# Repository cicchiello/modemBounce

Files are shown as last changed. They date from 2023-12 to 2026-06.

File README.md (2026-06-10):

# modemBounce

A home-network monitor that automatically power-cycles the cable modem or Wi-Fi router when connectivity problems are detected. The device periodically pings four targets — router, modem, an internet IP, and a DNS hostname. If any check fails repeatedly, the corresponding device is power-cycled through a normally-closed solid-state relay and an alert email is sent.

The hardware is an **Adafruit Feather M0** (SAMD21 + ATWINC1500 Wi-Fi), housed in a laser-cut enclosure. See `schematic.txt` for the circuit. An older Raspberry Pi proof-of-concept lives in `rpi/` but is not maintained.

---

## Hardware

### Bill of Materials

| Qty | Component | Notes |
|-----|---|---|
| 1 | Adafruit Feather M0 WiFi (ATWINC1500) | MCU + Wi-Fi |
| 2 | Berm KB25DA normally-closed SSR | 3–32 V DC input, 25 A AC output |
| 2 | 2N2222 NPN transistor | Low-side SSR driver (one per SSR) |
| 2 | 2.2 kΩ resistor, 1/4 W | 2N2222 base resistor |
| 1 | RGB LED, 5 mm, common cathode | Status indicator |
| 1 | 470 Ω resistor, 1/4 W | LED common-cathode current-limiting |
| 1 | Tactile push button, normally open | Reset + factory-reset input (see schematic) |
| 1 | Capacitor | AC-couples button press to Feather RESET pin for momentary reset pulse |
| 1 | USB wall adapter (disassembled) | Wired internally to post-fuse AC; 5 V DC output wired directly to Feather VUSB header pin |
| 1 | Protoboard | Hand-assembled PCB carrying the Feather and all low-voltage components |

See `schematic.txt` for wiring details. The mains hot feed passes through a 10 A fuse before splitting to both SSRs. Neutral runs straight through to both outlets; only the hot conductor is switched.

### Enclosure

The enclosure is entirely laser-cut from **Delrin** (acetal/POM), chosen for its electrical insulation and self-extinguishing properties. All panels and internal dividers are Delrin; there are no metal structural parts.

The interior is divided into **three compartments** by two internal divider panels:

| Compartment | Contents |
|---|---|
| Low-voltage | Protoboard PCB (Feather M0 + SSR drivers + LED + reset button) |
| High-voltage mixed | SSRs, disassembled USB wall-wart, incoming mains cable |
| AC outlets | Modem and router plugs, 10 A fuse |

The primary intent is HV/LV isolation; three compartments emerged naturally from the physical layout of the components.

FreeCAD source (`bouncy_v1.2.FCStd`) and laser-cut SVG panel exports are in `enclosure/svg-output/`. Interior divider profiles are `interior-short-v1.2.svg` and `interior-long-v1.2.svg`.

---

## Software components

| Location | Description |
|---|---|
| `feather/bouncy/` | Arduino/C++ firmware (current implementation) |
| `iot-services/email-relay/` | LAN email-relay service, Docker, runs on pi-nas |
| `rpi/` | Legacy Raspberry Pi proof-of-concept — not maintained |

---

## Firmware setup

### Arduino IDE libraries

Install via *Sketch → Include Library → Manage Libraries* or as ZIP files:

- **WiFi101** — ATWINC1500 driver (Arduino)
- **FlashStorage_SAMD** — EEPROM emulation in SAMD21 flash
- **arduinolibs** suite by rweather — provides `Crypto`, `AES`, `CTR`, `SHA256`

Board: *Adafruit SAMD Boards → Adafruit Feather M0*

### Secrets file

Edit `feather/bouncy/arduino_secrets.h`:

| Symbol | Purpose |
|---|---|
| `SECRET_SSID` / `SECRET_PASS` | Home Wi-Fi creds — used only in non-PROD test modes for direct-connect |
| `LOG_HOST/PORT/PATH`, `SECRET_LOGGING_KEY` | HTTP log service on pi-nas (port 8091) |
| `EMAIL_HOST/PORT/PATH`, `SECRET_EMAIL_KEY` | email-relay service on pi-nas (port 8093) |
| `SECRET_WIFI_ENC_KEY` | 16-byte AES-128 key for flash credential storage |
| `SECRET_WIFI_MAC_KEY` | 32-byte HMAC-SHA256 key for flash credential authentication |

Generate random keys:
```bash
openssl rand -hex 16    # → SECRET_WIFI_ENC_KEY (format as byte array)
openssl rand -hex 32    # → SECRET_WIFI_MAC_KEY
openssl rand -hex 24    # → shared keys for logging and email-relay
```

The `SHARED_KEY` value in `iot-services/email-relay/.env` must match `SECRET_EMAIL_KEY`.

### Build and flash

1. Open `feather/bouncy/bouncy.ino` in Arduino IDE.
2. Select *Tools → Board → Adafruit Feather M0*.
3. Select the correct serial port.
4. Click **Upload**.

---

## First-time setup (provisioning)

On first boot — or after a factory reset — there are no stored Wi-Fi credentials. The device enters provisioning mode automatically.

1. **LED goes blinking-red.** The Feather broadcasts a Wi-Fi network named **`Bouncy-Setup`**.
2. Connect a phone or laptop to `Bouncy-Setup`.
3. Open a browser and go to **`http://192.168.1.1/`**.
4. Enter your home Wi-Fi SSID and password.
5. Choose a **run mode** — use *Normal production mode* for permanent installation.
6. Tap **Save WiFi Settings**. The LED goes blue as the device connects.
7. Disconnect from `Bouncy-Setup`. The Feather joins your home network, **LED turns green**, and monitoring begins.

Run mode applies to the current session only; the device boots into `PROD` mode if it has valid credentials persisted. Test modes are intended for bench testing.

---

## Factory reset

The reset button is AC-coupled through a capacitor to the Feather's RESET pin, so any press immediately reboots the device. On startup the firmware checks whether the button is still held (via pin **A0**, INPUT_PULLUP):

- **Brief press / release before 5 s** — normal reboot, credentials intact.
- **Hold for 5 s** — Stored Wi-Fi credentials are erased and the device re-enters provisioning mode (with flasing-red indicator).

---

## Normal operation

| LED | Meaning |
|-----|---|
| Green | Connected and monitoring normally |
| Blue | Connecting / reconnecting to Wi-Fi |
| Red (flashing) | Provisioning mode — AP `Bouncy-Setup` is up; open `http://192.168.1.1` to configure |
| Red (steady) | Problem detected; bouncing a device |

The device checks connectivity every **30 minutes** (2 minutes in test modes):

1. Wi-Fi AP connection
2. Ping router — `10.0.0.1`
3. Ping modem — `192.168.100.1`
4. Ping internet — `8.8.8.8`
5. DNS resolution — `google.com`

Each failing check is retried up to **5 times** at 1-minute intervals. After 5 consecutive failures:

- Router ping failure → router is power-cycled
- Modem / internet / DNS failure → cable modem is power-cycled

After a bounce, the device waits **3.5 minutes** for the device to reinitialize, then sends an alert email and resumes monitoring.

---

## email-relay service

The email-relay is a small HTTP service on **pi-nas** (`10.0.0.214:8093`) that lets the Feather send alert emails without embedding SMTP credentials in the firmware. It runs in Docker.

See [`iot-services/email-relay/README.md`](iot-services/email-relay/README.md) for full setup, configuration, and testing instructions.

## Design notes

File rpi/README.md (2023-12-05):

modemBounce.py
   - executed every 15 minutes (per crontab)
      (It can't be much more frequently without more work -- the whole cycle takes max about 10 minutes)
   - when a problem is detected, it will attempt to power down, then back up the modem's A/C outlet

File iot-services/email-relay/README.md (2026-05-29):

# email-relay

`email-relay` is a small LAN-only HTTP service that lets the Feather M0 send monitoring emails without embedding SMTP credentials in the firmware.

The Feather sends a simple HTTP `POST` request to `pi-nas`; this service validates a shared key and sends the email through the configured SMTP account.

---

## Purpose

The Feather M0 is a small monitoring device. It should be able to report notable events by email, but it should **not** know the SMTP server password.

This service provides a local relay:

```text
Feather M0
  HTTP POST /send
  shared-key header
  JSON body with subject/message
        |
        v
pi-nas email-relay
  validates request
  sends email using SMTP credentials stored on pi-nas
        |
        v
configured email recipients
```

---

## Host environment

This service is intended to run on:

- Host: `pi-nas`
- Hardware: Raspberry Pi 5
- NAS manager: OpenMediaVault
- Container runtime: Docker / OMV Compose
- LAN IP: `10.0.0.214`
- Service port: `8093`

The service listens on:

```text
http://10.0.0.214:8093/send
```

Only HTTP `POST` to `/send` is supported.

---

## Repository layout

```text
~/workspace/modemBounce/iot-services/email-relay/
  Dockerfile
  docker-compose.yml
  email_relay.py
  .env              # local secrets; not committed
  .env.example      # documented example; safe to commit
  .gitignore
  README.md
```

Convenience symlink:

```text
/opt/pi-nas-services/email-relay -> /home/joe/workspace/modemBounce/iot-services/email-relay
```

The git repo is the preferred authoritative source for the service.

---

## API

### Endpoint

```http
POST /send
```

### Required header

```http
X-Email-Relay-Key: <shared-key>
```

The key is stored in `.env` as:

```text
SHARED_KEY=...
```

The Feather firmware should store the same value in `arduino_secrets.h`, for example:

```cpp
#define SECRET_EMAIL_RELAY_KEY "..."
```

### Request body

The request body is JSON:

```json
{
  "subject": "Feather alert",
  "message": "Monitoring event details go here."
}
```

The service intentionally does **not** accept a `to` field from the Feather. Recipients are fixed in `.env` so a compromised or buggy device cannot send arbitrary email to arbitrary recipients.

### Success response

```http
HTTP/1.0 200 OK
Content-Type: application/json
```

```json
{"status": "sent"}
```

### Common error responses

```text
401 Unauthorized       missing/wrong shared key
404 Not Found          path other than /send
400 Bad Request        invalid JSON or missing fields
413 Payload Too Large  request body too large
502 Bad Gateway        SMTP send failed
```

---

## Configuration

Runtime configuration is stored in `.env`.

The file is intentionally ignored by git.

Example:

```text
SHARED_KEY=replace-with-random-hex-key

SMTP_HOST=smtp.gmail.com
SMTP_PORT=587
SMTP_STARTTLS=true
SMTP_USER=your-smtp-username
SMTP_PASS=your-smtp-password-or-app-password

MAIL_FROM=pi-nas@example.com
MAIL_TO=you@example.com,alternate@example.com

SUBJECT_PREFIX=[Bouncy] 
```

### Settings

| Variable | Purpose |
|---|---|
| `SHARED_KEY` | HTTP shared key required from the Feather |
| `SMTP_HOST` | SMTP server hostname |
| `SMTP_PORT` | SMTP server port, usually `587` for STARTTLS or `465` for SMTP-over-SSL |
| `SMTP_STARTTLS` | `true` for STARTTLS on port 587 |
| `SMTP_USER` | SMTP username |
| `SMTP_PASS` | SMTP password or app password |
| `MAIL_FROM` | Sender address |
| `MAIL_TO` | Comma-separated recipient list |
| `SUBJECT_PREFIX` | Prefix added to every email subject |
| `MAX_BODY_BYTES` | Optional HTTP request size limit |
| `MAX_SUBJECT_CHARS` | Optional subject length limit |
| `MAX_MESSAGE_CHARS` | Optional message length limit |

---

## SMTP configuration source

This service was configured using the same SMTP account as OMV notifications.

OMV notification config can be inspected with:

```bash
sudo omv-confdbadm read conf.system.notification.email | python3 -m json.tool
```

OMV redacts the password in that output. The real SMTP password or Gmail app password still needs to be entered manually into `email-relay/.env`.

For the current setup, the non-secret values are based on OMV’s email notification settings:

```text
SMTP_HOST=smtp.gmail.com
SMTP_PORT=587
SMTP_STARTTLS=true
SMTP_USER=<same Gmail account used by OMV>
MAIL_FROM=<same sender used by OMV>
MAIL_TO=<configured monitoring recipients>
```

Do not paste or commit the SMTP password.

---

## Creating `.env`

Copy the example:

```bash
cp .env.example .env
chmod 600 .env
```

Generate a shared key:

```bash
openssl rand -hex 24
```

Edit `.env`:

```bash
nano .env
```

Keep `.env` out of git.

Check that `.env` is ignored:

```bash
git status --ignored
```

---

## Docker Compose

The service runs with Docker Compose.

Important settings in `docker-compose.yml`:

```yaml
ports:
  - "10.0.0.214:8093:8093"
```

This binds the service to the NAS LAN IP instead of all interfaces.

```yaml
restart: unless-stopped
```

This causes the container to restart after reboot unless it was explicitly stopped.

The service does not need a data volume. It only stores configuration in `.env` and sends emails through SMTP.

---

## Basic commands

Run commands from the service directory:

```bash
cd /home/joe/workspace/modemBounce/iot-services/email-relay
```

### Start or rebuild

```bash
sudo docker compose up -d --build
```

### Stop

```bash
sudo docker compose down
```

### Show container status

```bash
sudo docker ps --filter name=email-relay
```

Expected port binding:

```text
10.0.0.214:8093->8093/tcp
```

### View logs

```bash
sudo docker compose logs
```

Follow logs live:

```bash
sudo docker compose logs -f
```

### Check restart policy

```bash
sudo docker inspect -f '{{.HostConfig.RestartPolicy.Name}}' email-relay
```

Expected:

```text
unless-stopped
```

---

## Testing

### Unauthorized request test

This should fail with `401 Unauthorized`:

```bash
curl -i \
  -X POST \
  -H 'X-Email-Relay-Key: wrong-key' \
  -H 'Content-Type: application/json' \
  --data '{"subject":"test","message":"this should be rejected"}' \
  http://10.0.0.214:8093/send
```

Expected:

```text
HTTP/1.0 401 Unauthorized
```

### Authorized send test

This reads the shared key from `.env` without printing it:

```bash
curl -i \
  -X POST \
  -H "X-Email-Relay-Key: $(sed -n 's/^SHARED_KEY=//p' .env)" \
  -H 'Content-Type: application/json' \
  --data '{"subject":"email-relay test","message":"This is a test message from the pi-nas email-relay service."}' \
  http://10.0.0.214:8093/send
```

Expected:

```text
HTTP/1.0 200 OK
```

```json
{"status": "sent"}
```

Then confirm the email arrives at the configured recipients.

### If the send fails

Check the service logs:

```bash
sudo docker compose logs --tail=50
```

A `502` response means the HTTP request was accepted but the SMTP send failed.

---

## Feather client shape

The Feather calls:

```text
http://10.0.0.214:8093/send
```

with:

```http
X-Email-Relay-Key: <shared-key>
Content-Type: application/json
```

and a body like:

```json
{
  "subject": "Feather alert",
  "message": "The monitoring device detected an event."
}
```

The working firmware module is `EmailRelay.{cpp,h}`. It should return success only when the HTTP status is `200`.

Example use:

```cpp
EmailRelay Mailer("10.0.0.214", 8093, "/send", SECRET_EMAIL_RELAY_KEY);

if (Mailer.send("Feather test", "This is a test email from the Feather.")) {
  Log.println("EmailRelay test sent");
} else {
  Log.println("EmailRelay test failed");
}
```

---

## OMV Compose integration

The service is imported into OMV Compose so it appears in the OMV UI.

OMV path pattern:

```text
/srv/dev-disk-by-uuid-1b03c883-24b8-4bbc-9e3f-9fdc70389470/pi-nas/services-compose/email-relay/
```

OMV generates files such as:

```text
email-relay.yml
email-relay.env
compose.yml
.env
```

Those files are generated by OMV. Do not edit them directly.

Preferred source of truth:

```text
/home/joe/workspace/modemBounce/iot-services/email-relay
```

If `docker-compose.yml` or `.env` changes, update the repo first, then update/re-import through the OMV UI so OMV’s generated copy stays synchronized.

---

## Comparing repo and OMV copy

Compare Compose YAML:

```bash
sudo diff -u \
  /home/joe/workspace/modemBounce/iot-services/email-relay/docker-compose.yml \
  /srv/dev-disk-by-uuid-1b03c883-24b8-4bbc-9e3f-9fdc70389470/pi-nas/services-compose/email-relay/email-relay.yml
```

A difference consisting only of OMV’s generated header is expected.

Compare the shared key without printing it:

```bash
repo_key_hash="$(
  sed -n 's/^SHARED_KEY=//p' /home/joe/workspace/modemBounce/iot-services/email-relay/.env |
  sha256sum |
  awk '{print $1}'
)"

omv_key_hash="$(
  sudo sed -n 's/^SHARED_KEY=//p' /srv/dev-disk-by-uuid-1b03c883-24b8-4bbc-9e3f-9fdc70389470/pi-nas/services-compose/email-relay/email-relay.env |
  sha256sum |
  awk '{print $1}'
)"

if [ "$repo_key_hash" = "$omv_key_hash" ]; then
  echo "SHARED_KEY values match"
else
  echo "SHARED_KEY values differ"
fi
```

---

## Security notes

This service is designed for trusted LAN use.

Important limits:

- The Feather does not get SMTP credentials.
- The service is bound only to `10.0.0.214:8093`.
- The HTTP endpoint requires `X-Email-Relay-Key`.
- Recipients are fixed in `.env`.
- The service does not accept arbitrary recipient addresses from the request body.
- HTTPS is not used; this is acceptable only because the service is LAN-only.

Protect these files:

```text
.env
OMV-generated email-relay.env
```

They contain secrets.

---

## Rate limiting

The current service does not implement persistent rate limiting.

The Feather firmware should avoid sending repeated emails in a tight loop. For example:

- send only on state transitions
- enforce a minimum interval between alerts
- use logging for frequent status messages
- use email only for significant monitoring events

If needed later, `email_relay.py` can add in-memory rate limiting such as “no more than one email every N seconds.”

---

## Troubleshooting

### Container is not running

```bash
sudo docker ps -a --filter name=email-relay
sudo docker compose logs --tail=50
```

### Port is not listening

```bash
sudo ss -ltnp | grep 8093
```

Expected listener:

```text
10.0.0.214:8093
```

### Unauthorized request

Check that the Feather’s `SECRET_EMAIL_RELAY_KEY` matches `.env`:

```text
SHARED_KEY=...
```

Do not paste the key into logs or chat.

### SMTP failure

Look at Docker logs:

```bash
sudo docker compose logs --tail=50
```

Possible causes:

- wrong SMTP password/app password
- Gmail app password revoked
- wrong SMTP port/TLS setting
- network or DNS issue on `pi-nas`
- SMTP provider rate limiting or rejecting the sender

### Email delivered to only one recipient

`MAIL_TO` is comma-separated:

```text
MAIL_TO=person1@example.com,person2@example.com
```

Make sure there are no unexpected quotes around the value.

---

## Git notes

Files that should be committed:

```text
Dockerfile
docker-compose.yml
email_relay.py
.env.example
.gitignore
README.md
```

Files that should not be committed:

```text
.env
*.log
__pycache__/
```

Before committing, check for accidental secrets:

```bash
git status
git diff --cached
grep -RIn --exclude-dir=.git \
  -e 'SHARED_KEY=' \
  -e 'SMTP_PASS=' \
  -e 'SECRET_EMAIL_RELAY_KEY' \
  .
```

Expect `SHARED_KEY=` and `SMTP_PASS=` only in `.env` or examples with placeholder values. Do not commit real secret values.

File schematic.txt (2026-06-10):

==============================================================================
  modemBounce  ·  Feather M0 (SAMD21 / ATWINC1500)  ·  Circuit Schematic
==============================================================================

  SSRs: Berm KB25DA (3-32 V DC input, 24-480 V AC / 25 A output, NC type)
  RGB LED: common cathode; single 470 ohm resistor on cathode path
  MCU power: disassembled USB wall-wart wired internally to post-fuse AC;
             5 V DC output wired directly to Feather VUSB header pin
  Construction: hand-assembled protoboard PCB

  AC MAINS WIRING (120 VAC)
  --------------------------

   Mains inlet
     L (hot) ---- [10 A fuse] ---+--- SSR1 KB25DA in (NC) --- SSR1 out --- ROUTER plug L
                                 |
                                 +--- SSR2 KB25DA in (NC) --- SSR2 out --- MODEM plug L
                                 |
                                 +--- USB wall-wart AC in (L)
                                           |
     N (neutral) ----------+--------------+--- USB wall-wart AC in (N)
                           |                        |
                           |               USB wall-wart out: 5 V DC
                           |                        |
                           +---- ROUTER plug N      +---> 5 V rail (protoboard)
                           |
                           +---- MODEM plug N

  LOW-VOLTAGE CIRCUIT  (protoboard)
  ----------------------------------

  5 V rail ---+--- Feather VUSB pin  (powers MCU; also source for SSR drivers)
              |
              +--- SSR1 KB25DA input (+)
              |
              +--- SSR2 KB25DA input (+)

  +----------------------------------------------------------------------+
  | Feather M0 WINC1500 module (SAMD21 / ATWINC1500)                     |
  |                                                                      |
  |  -- Reset / Factory-Reset Button ----------------------------        |
  |                                                                      |
  |                        +-------- [~0.47 uF] ---- RESET pin           |
  |   A0 (INPUT_PULLUP) ---+                                             |
  |                        +--------------------------------- GND        |
  |                                [BTN, NO, single-throw]               |
  |                                                                      |
  |   Press: cap pulse resets Feather; firmware checks A0 on boot        |
  |   Hold 5 s after reset: factory reset (clears Wi-Fi creds)           |
  |                                                                      |
  |  -- RGB Status LED (common cathode, one color at a time) ----        |
  |                                                                      |
  |   A4 ------------------------------------ R anode                    |
  |   A1 ------------------------------------ G anode                    |
  |   A2 ------------------------------------ B anode                    |
  |                             common cathode -- [470 ohm] -- GND       |
  |                                                                      |
  |  -- SSR Driver - Router  (pin 5, low-side NPN) -------------         |
  |                                                                      |
  |   pin 5 -- [2.2 kohm] -- Q1 base (2N2222)                            |
  |                           Q1 emitter --------- GND                   |
  |   5 V rail -------------- SSR1 KB25DA input (+)                      |
  |                           Q1 collector ------- SSR1 KB25DA input (-) |
  |                                                                      |
  |  -- SSR Driver - Modem  (pin A5, low-side NPN) -------------         |
  |                                                                      |
  |   A5 ----- [2.2 kohm] -- Q2 base (2N2222)                            |
  |                           Q2 emitter --------- GND                   |
  |   5 V rail -------------- SSR2 KB25DA input (+)                      |
  |                           Q2 collector ------- SSR2 KB25DA input (-) |
  |                                                                      |
  |  -- ATWINC1500 Wi-Fi (on-module; no external wiring) ---------       |
  |   WiFi.setPins(CS=8, IRQ=7, RST=4, EN=2)                             |
  +----------------------------------------------------------------------+

  NORMALLY-CLOSED SSR LOGIC
  -------------------------
  The Berm KB25DA has both normally-closed (NC) and normally-open (NO)
  pins, but NC mode is used exclusively: AC passes through by default.
  The Feather only has to act to interrupt power, not to restore it.
  If the Feather loses power or crashes, both outlets remain energized.

    Feather pin LOW  (0 V)   -> Q off -> SSR de-energized -> CLOSED -> AC ON
    Feather pin HIGH (3.3 V) -> Q sat -> SSR energized    -> OPEN   -> AC OFF

  Both SSR output pins are initialized LOW in setup(), so AC is on at boot.

  ENCLOSURE
  ---------
  Entirely laser-cut Delrin (acetal/POM) — electrically insulating and
  self-extinguishing. Three internal compartments provide HV/LV isolation:

    [Low-voltage]          [High-voltage mixed]        [AC outlets]
    Protoboard PCB         SSRs                        Modem plug
    Feather M0             USB wall-wart               Router plug
    LED, button            Incoming mains cable        10 A fuse

  The two internal divider panels (interior-short, interior-long) physically
  separate the low-voltage PCB from all mains-potential conductors.

  AC SAFETY NOTE
  --------------
  The 10 A fuse protects the entire hot feed before it reaches the SSRs or
  the internal wall-wart. Neutral is passed through uninterrupted. All
  mains-potential conductors are contained within the two HV compartments
  and are physically isolated from the low-voltage PCB by Delrin dividers.

==============================================================================

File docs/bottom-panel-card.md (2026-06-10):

# Bottom-panel reference card

Print at **85 × 54 mm** (business card), laminate, and affix to the bottom of the enclosure.

---

<!-- ============================================================
     CARD CONTENT BELOW — print/render from this point
     Suggested: render to PDF at 85×54 mm, ~9 pt font
     ============================================================ -->

---

**BOUNCY** · Network Monitor v1.2

---

**LED STATUS**

|-----------------|--------------------------------|
| 🟢 Green        | Monitoring normally            |
| 🔵 Blue         | Connecting to Wi-Fi            |
| 🔴 Red flashing | Provisioning — see setup below |
| 🔴 Red steady   | Bouncing a device              |
---------------------------------------------------|

**NORMAL OPERATION**  
Checks every 30 min: Wi-Fi → router → modem → 8.8.8.8 → DNS  
Retries 5× before bouncing. Alert email sent after each bounce.

---

**FIRST-TIME SETUP / AFTER RESET**  
1. Join Wi-Fi network: **`Bouncy-Setup`**  
2. Open browser → **`http://192.168.1.1`**  
3. Enter SSID, password, run mode → Save

---

**FACTORY RESET**  
Hold reset button **5 seconds** (until LED flashes red)  
Erases stored Wi-Fi credentials → re-enters setup

---

*modemBounce · github.com/jcicchiello · 2026*

---

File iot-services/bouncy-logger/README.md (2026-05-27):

# modemBounce bouncy-logger

`modemBounce/iot-services/bouncy-logger` is a very small HTTP logging service to be run on `pi-nas`.

It accepts HTTP `PUT` requests from LAN devices, checks a shared secret key, and appends the request body to a log file stored on the NAS RAID volume.

The original target client is an Arduino-like device that periodically sends a short string to be logged.

---

## Host environment

This service is intended to run on:

- Host: `pi-nas`
- Hardware: Raspberry Pi 5
- OS: Debian / Raspberry Pi OS based OMV host
- NAS manager: OpenMediaVault
- Docker: installed through OMV Extras / OMV Compose plugin
- LAN IP: `10.0.0.214`
- Service port: `8091`

The service listens on:

```text
http://10.0.0.214:8091/log
```

Only HTTP `PUT` is accepted.

---

## Repository layout

```text
~/workspace/modemBounce/iot-services/bouncy-logger/
  Dockerfile
  docker-compose.yml
  logger.py
  .env              # local secret; not committed
  .gitignore
  README.md
```

There is also a symlink:

```text
/opt/pi-nas-services/bouncy-logger -> /home/joe/workspace/modemBounce/iot-services/bouncy-logger
```

The git repo is the preferred authoritative source for the service.

---

## Runtime data location

The log file is stored on the NAS RAID volume here:

```text
/srv/dev-disk-by-uuid-1b03c883-24b8-4bbc-9e3f-9fdc70389470/pi-nas/services-data/bouncy-logger/bouncy.log
```

Inside the Docker container, that directory is mounted as:

```text
/data
```

The logger writes to:

```text
/data/bouncy.log
```

This keeps log data off the Raspberry Pi SD card.

---

## Security model

This service is intentionally simple and LAN-only.

It does not use HTTPS.

Each request must include a shared key in the HTTP header:

```http
X-Log-Key: <shared-key>
```

The key is stored locally in `.env`:

```text
SHARED_KEY=...
```

The `.env` file is intentionally ignored by git.

Do not commit `.env`.

Do not put the key in the URL. Use the HTTP header instead.

---

## Current Docker Compose configuration

The service is defined in `docker-compose.yml`.

Important settings:

```yaml
ports:
  - "10.0.0.214:8091:8091"
```

This binds the service to the NAS LAN IP instead of all interfaces.

```yaml
restart: unless-stopped
```

This causes the container to restart automatically after reboot, unless it was manually stopped.

```yaml
volumes:
  - /srv/dev-disk-by-uuid-1b03c883-24b8-4bbc-9e3f-9fdc70389470/pi-nas/services-data/bouncy-logger:/data
```

This stores logs on the RAID-backed NAS volume.

---

## Basic commands

Run these from the repo directory:

```bash
cd ~/workspace/modemBounce/iot-services/bouncy-logger
```

### Show running container

```bash
sudo docker ps --filter name=bouncy-logger
```

### Start or rebuild service

```bash
sudo docker compose up -d --build
```

Use this after changing `logger.py`, `Dockerfile`, or `docker-compose.yml`.

### Stop service

```bash
sudo docker compose down
```

Note: because the restart policy is `unless-stopped`, a container stopped with `docker compose down` will not automatically come back until started again.

### View container logs

```bash
sudo docker compose logs
```

Follow logs live:

```bash
sudo docker compose logs -f
```

### Check restart policy

```bash
sudo docker inspect -f '{{.HostConfig.RestartPolicy.Name}}' bouncy-logger
```

Expected output:

```text
unless-stopped
```

---

## Testing

### Unauthorized request test

This should fail with HTTP `401 Unauthorized`:

```bash
curl -i \
  -X PUT \
  -H 'X-Log-Key: wrong-key' \
  --data 'this should be rejected' \
  http://10.0.0.214:8091/log
```

Expected result:

```text
HTTP/1.0 401 Unauthorized
```

### Authorized request test

This sends a test log message without displaying the key:

```bash
curl -i \
  -X PUT \
  -H "X-Log-Key: $(sed -n 's/^SHARED_KEY=//p' .env)" \
  --data 'test log message from curl' \
  http://10.0.0.214:8091/log
```

Expected result:

```text
HTTP/1.0 204 No Content
```

### Verify the log file

```bash
sudo tail -5 /srv/dev-disk-by-uuid-1b03c883-24b8-4bbc-9e3f-9fdc70389470/pi-nas/services-data/bouncy-logger/bouncy.log
```

Example log line:

```text
2026-05-27T14:56:12+00:00 10.0.0.x test log message from curl
```

Each line includes:

```text
UTC timestamp
source IP address
message body
```

---

## Arduino request shape

The Arduino should send an HTTP `PUT` request to:

```text
http://10.0.0.214:8091/log
```

With header:

```text
X-Log-Key: <shared-key>
```

And a short body string, for example:

```text
event=bounce count=123
```

Pseudo-code shape:

```cpp
http.begin("http://10.0.0.214:8091/log");
http.addHeader("X-Log-Key", "<shared-key>");
int rc = http.PUT("event=bounce count=123");
```

Expected success response:

```text
204 No Content
```

---

## OMV Compose UI integration

The service was originally created and tested from the command line in:

```text
/home/joe/workspace/modemBounce/iot-services/bouncy-logger
```

It was then imported into the OMV Compose plugin so OMV can display/manage it.

OMV Compose currently has its own generated copy under the `pi-nas` shared folder:

```text
/srv/dev-disk-by-uuid-1b03c883-24b8-4bbc-9e3f-9fdc70389470/pi-nas/bouncy-logger/bouncy-logger.yml
/srv/dev-disk-by-uuid-1b03c883-24b8-4bbc-9e3f-9fdc70389470/pi-nas/bouncy-logger/bouncy-logger.env
```

Those files are generated by OMV.

Do not edit the OMV-generated `.yml` directly. It contains a warning similar to:

```text
This file is auto-generated by openmediavault.
WARNING: Do not edit this file, your changes will get lost.
```

### Source of truth

The preferred source of truth is this git repo:

```text
/home/joe/workspace/modemBounce/iot-services/bouncy-logger
```

OMV's copy is useful for display/status and optional start/stop operations.

If the Compose file or environment changes, update the repo first, then update/re-import through the OMV UI so the OMV copy stays synchronized.

---

## Checking whether repo and OMV copy match

Compare Compose definitions:

```bash
sudo diff -u \
  /home/joe/workspace/modemBounce/iot-services/bouncy-logger/docker-compose.yml \
  /srv/dev-disk-by-uuid-1b03c883-24b8-4bbc-9e3f-9fdc70389470/pi-nas/bouncy-logger/bouncy-logger.yml
```

A difference consisting only of OMV's generated comment header is expected.

Compare environment files without printing the secret:

```bash
sudo cmp -s \
  /home/joe/workspace/modemBounce/iot-services/bouncy-logger/.env \
  /srv/dev-disk-by-uuid-1b03c883-24b8-4bbc-9e3f-9fdc70389470/pi-nas/bouncy-logger/bouncy-logger.env \
  && echo "env files match" \
  || echo "env files differ"
```

Note: OMV's env file may contain comment headers, so a literal `cmp` may report differences even when the actual `SHARED_KEY=...` value matches.

To compare only the key values without displaying them:

```bash
repo_key_hash="$(
  sed -n 's/^SHARED_KEY=//p' /home/joe/workspace/modemBounce/iot-services/bouncy-logger/.env |
  sha256sum |
  awk '{print $1}'
)"

omv_key_hash="$(
  sudo sed -n 's/^SHARED_KEY=//p' /srv/dev-disk-by-uuid-1b03c883-24b8-4bbc-9e3f-9fdc70389470/pi-nas/bouncy-logger/bouncy-logger.env |
  sha256sum |
  awk '{print $1}'
)"

if [ "$repo_key_hash" = "$omv_key_hash" ]; then
  echo "SHARED_KEY values match"
else
  echo "SHARED_KEY values differ"
fi
```

---

## Rotating the shared key

Generate a new key:

```bash
openssl rand -hex 24
```

Edit `.env`:

```bash
nano .env
```

Update:

```text
SHARED_KEY=<new-key>
```

Restart the service from the repo:

```bash
sudo docker compose up -d --build
```

Then update/re-import the OMV Compose entry through the OMV UI so OMV's stored environment matches.

After rotating the key, update the Arduino/device configuration.

---

## Docker storage note

Docker's image/container storage is currently:

```text
/var/lib/docker
```

This is on the Raspberry Pi SD card.

This is acceptable for this small service because:

- the image is small
- the container does not write significant data to its writable layer
- the log file is bind-mounted to the RAID volume

If many more containers are added later, consider moving Docker storage to the NAS volume or another suitable disk, but that is intentionally not done for this lightweight service.

---

## Log rotation

The current service appends to:

```text
bouncy.log
```

No application-level log rotation is implemented yet.

For low-rate Arduino logging, this may be fine for a long time.

If the log becomes large, add host-side `logrotate` later for:

```text
/srv/dev-disk-by-uuid-1b03c883-24b8-4bbc-9e3f-9fdc70389470/pi-nas/services-data/bouncy-logger/bouncy.log
```

Example future policy:

```text
rotate weekly
keep several compressed old logs
do not rotate if empty
create new log with appropriate ownership
```

---

## Troubleshooting

### Container is not running

```bash
sudo docker ps -a --filter name=bouncy-logger
```

Then inspect logs:

```bash
sudo docker compose logs
```

### Port not listening

```bash
sudo ss -ltnp | grep 8091
```

Expected listener:

```text
10.0.0.214:8091
```

### Bad key test succeeds unexpectedly

That should not happen. Check the `.env` file and Compose environment:

```bash
sudo docker inspect bouncy-logger | grep -A20 Env
```

Be careful: this may display the shared key.

### Good key test fails

Check that `.env` exists and contains `SHARED_KEY`:

```bash
ls -l .env
grep '^SHARED_KEY=' .env
```

Be careful when copying output because this displays the key.

### Log file not written

Check that the data directory exists:

```bash
sudo ls -ld /srv/dev-disk-by-uuid-1b03c883-24b8-4bbc-9e3f-9fdc70389470/pi-nas/services-data/bouncy-logger
```

Check the log file:

```bash
sudo ls -l /srv/dev-disk-by-uuid-1b03c883-24b8-4bbc-9e3f-9fdc70389470/pi-nas/services-data/bouncy-logger/bouncy.log
```

Check container logs:

```bash
sudo docker compose logs
```

---

## Git notes

Files that should be committed:

```text
Dockerfile
docker-compose.yml
logger.py
.gitignore
README.md
```

Files that should not be committed:

```text
.env
*.log
__pycache__/
```

Check status:

```bash
git status
```

Initialize repo, if not already done:

```bash
git init
git add Dockerfile docker-compose.yml logger.py .gitignore README.md
git commit -m "Initial bouncy logger service"
```

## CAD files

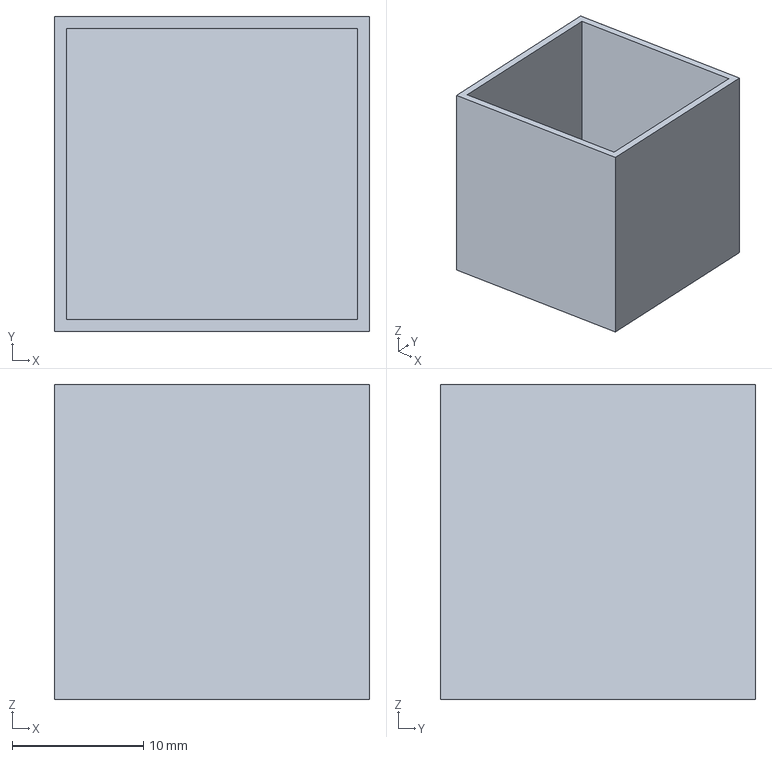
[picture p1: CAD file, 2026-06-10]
enclosure/box_w24.0_d24.0_t0.9_h24.0_b0.9.step
24.0 x 24.0 x 24.0 mm

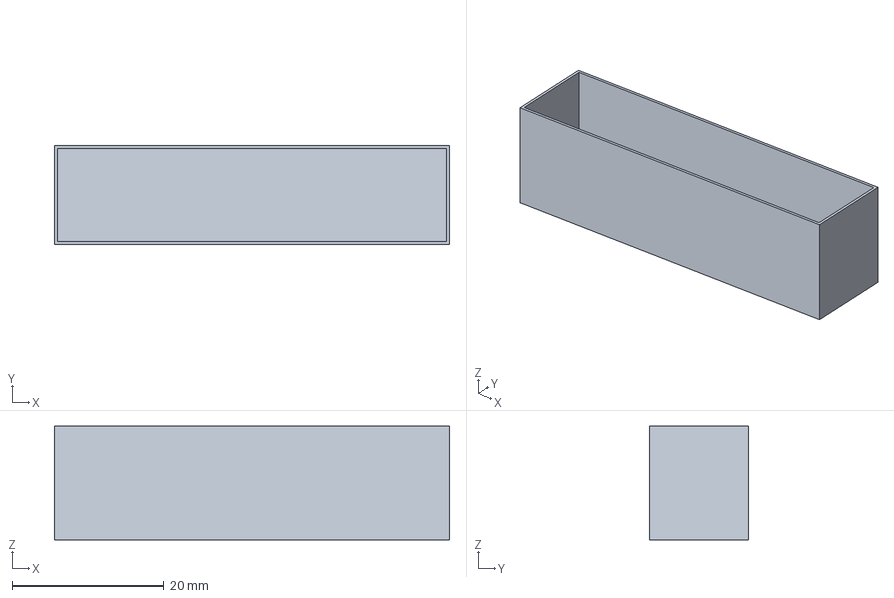
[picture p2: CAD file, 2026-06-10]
enclosure/box_w52.0_d13.0_t0.4_h15.0_b0.4.step
52.0 x 13.0 x 15.0 mm

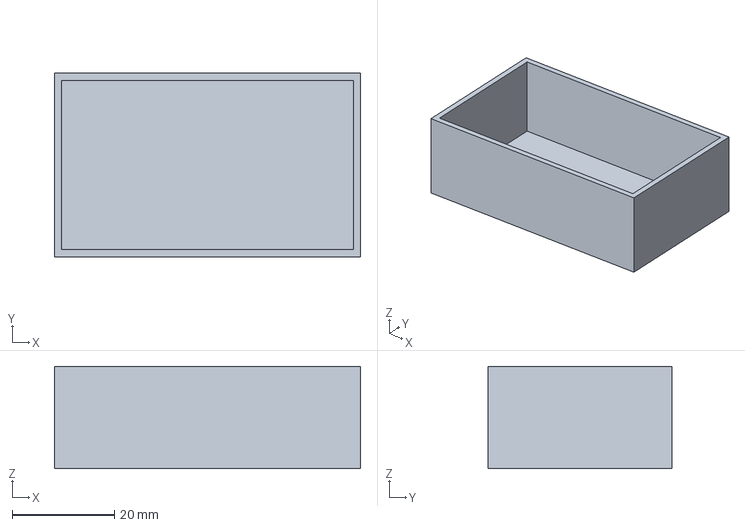
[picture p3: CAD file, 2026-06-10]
enclosure/box_w60.0_d36.0_t1.4_h20.0_b1.4.step
60.0 x 36.0 x 20.0 mm

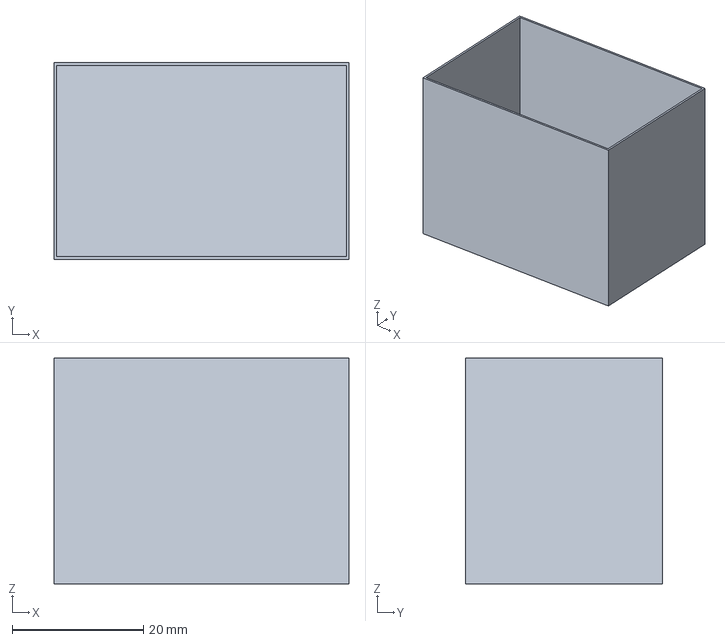
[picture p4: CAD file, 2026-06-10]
enclosure/box_w45.0_d30.0_t0.4_h34.4_b0.4.step
45.0 x 30.0 x 34.4 mm

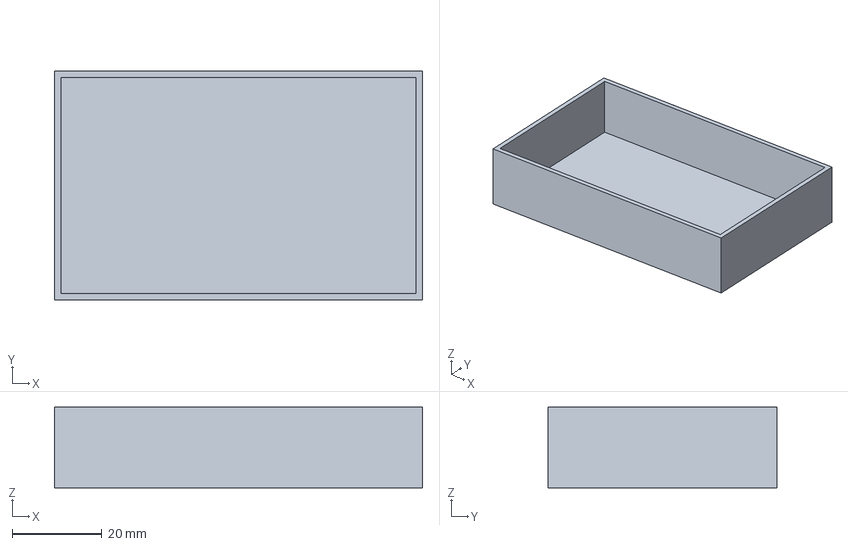
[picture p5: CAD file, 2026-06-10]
enclosure/box_w82.0_d51.0_t1.4_h18.0_b1.4.step
82.0 x 51.0 x 18.0 mm

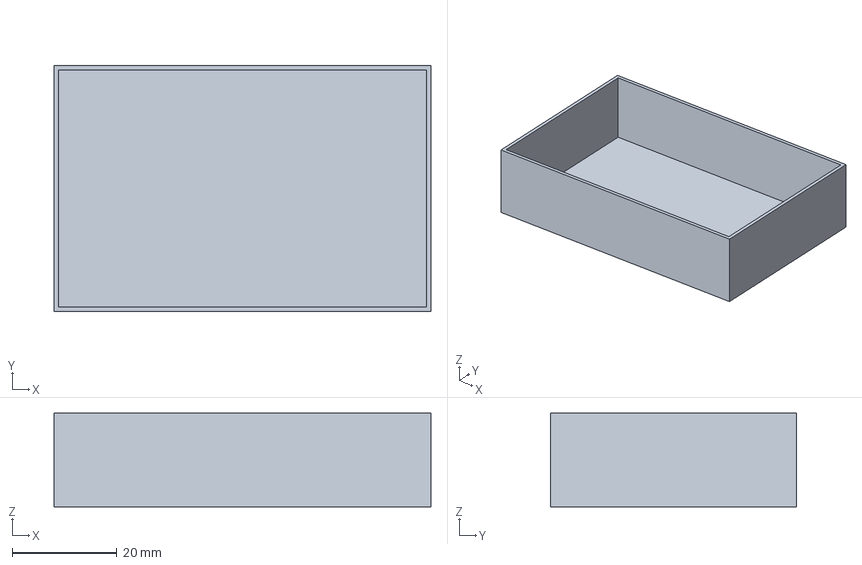
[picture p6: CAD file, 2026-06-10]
enclosure/box_w72.0_d47.0_t0.9_h17.9_b0.9.step
72.0 x 47.0 x 17.9 mm

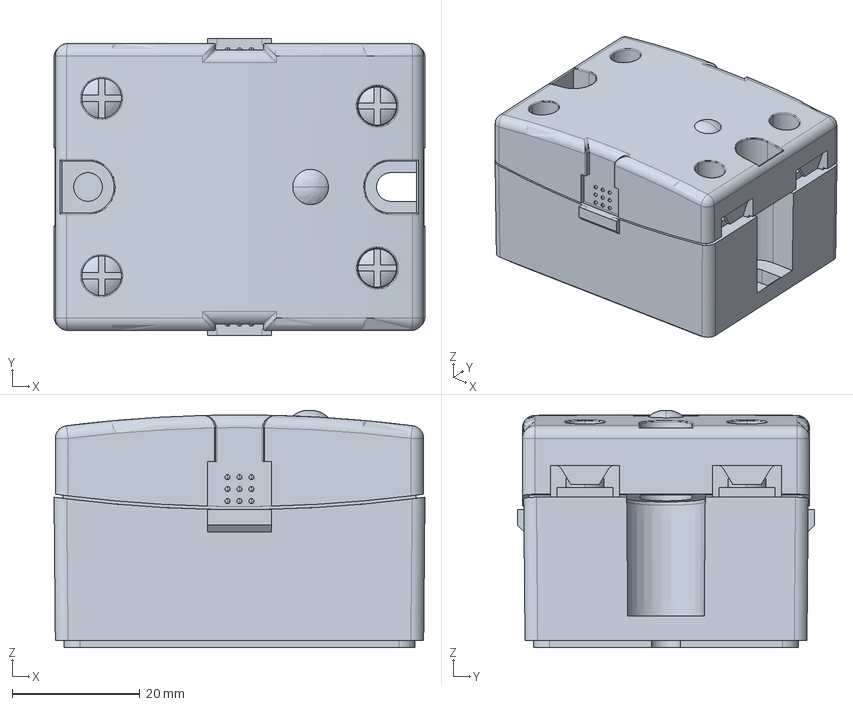
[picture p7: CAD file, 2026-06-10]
enclosure/c-1393030-7-b1-3d.stp
58.2 x 46.6 x 37.2 mm

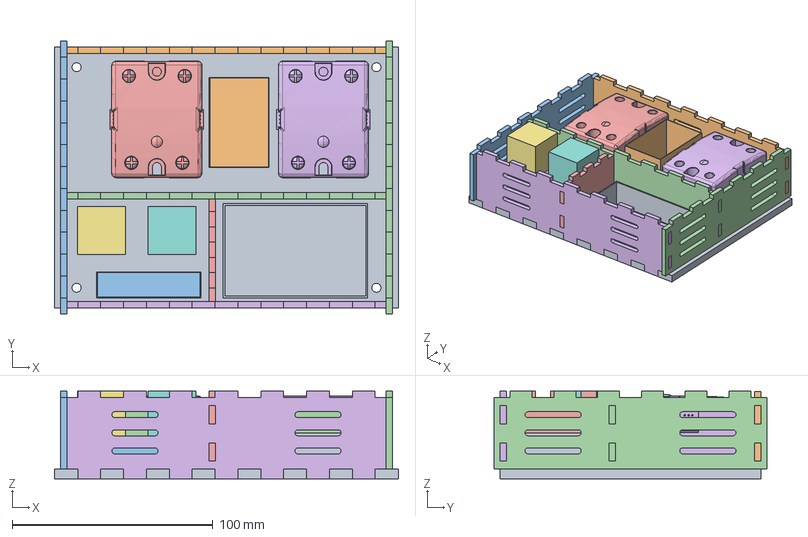
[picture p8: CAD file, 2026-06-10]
enclosure/bouncy_v1.2.FCStd
171.4 x 135.9 x 43.6 mm
SSR-modem
SSR-router
outlet-modem
outlet-router
proto-board
Supply 5V
fuse-holder

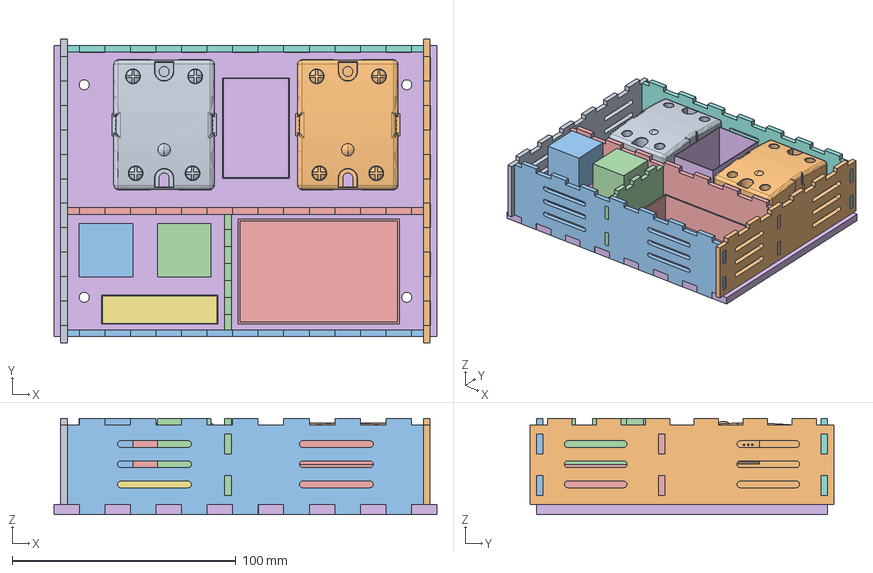
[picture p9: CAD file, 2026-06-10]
enclosure/bouncy.FCStd
171.0 x 135.9 x 43.0 mm
SSR-modem
SSR-router
outlet-modem
outlet-router
proto-board
fuse-holder
Supply 5V

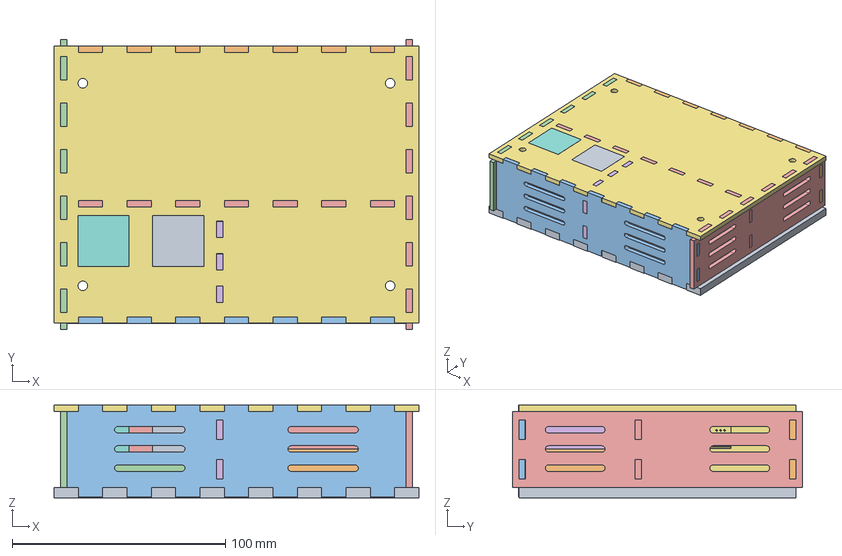
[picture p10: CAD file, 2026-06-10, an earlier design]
enclosure/bouncy_v1.1.FCStd
171.0 x 135.9 x 43.4 mm
SSR-modem
SSR-router
outlet-modem
outlet-router
proto-board
Supply 5V
fuse-holder

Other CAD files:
enclosure/svg-output/delrin_3_2mm.FCStd
enclosure/svg-output/delrin_4_9mm.FCStd

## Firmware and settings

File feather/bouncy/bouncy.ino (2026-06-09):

/*
  Periodically, in the following order, check that:
      1) the wifi router is reachable
      2) the cable modem is reachable
      3) a DNS server is reachable (IP 8.8.8.8)
  
  If any of those checks fail:
      1) trigger power-cycle of router
      2) trigger power-cycle of cable modem
      3) trigger power-cycle of cable modem

  Copyright Joe Cicchiello 2026

  ToDo:
    - consider OTA updates (mostly to enable testing in-circuit, but could change behavior later)
    - define and print enclosure
    - wire up and install circuit

*/


#include <SPI.h>
#include <WiFi101.h>
#include "HttpLogger.h"
#include "Logger.h"
#include "Connector.h"
#include "Indicator.h"
#include "EmailRelay.h"
#include "arduino_secrets.h" 

#define PROGNAME "Bouncy"


enum State {Initialize, Wait, Sleep, APConnect, RouterPing, ModemPing, InternetPing, DnsPing};

static Runtype sTest = PROD;
static State sState = Initialize;
static State sStateAfterWait = Initialize;
static long sWait_ms = 0;

#define TIME_BETWEEN_MONITOR_ATTEMPTS_ms (sTest == PROD ? 30*60*1000 : 2*60*1000) 
#define NUM_FAILURES_TO_BOUNCE (sTest == PROD ? 5 : 3)

static const IPAddress Internet() {return IPAddress(8,8,8,(sTest != test_IP ? 8 : 81));}
static const char *DNS() {return sTest != test_DNS ? "google.com" : "google.comfoo";}
static const IPAddress ModemIP() {return IPAddress(192,168,100, (sTest != test_MODEM ? 1 : 111));}
static const IPAddress RouterIP() {return IPAddress(10,0,0, (sTest != test_ROUTER ? 1 : 111));}

static HttpLogger sHttpLog(LOG_HOST, LOG_PORT, LOG_PATH, SECRET_LOGGING_KEY);
static Logger Log(&sHttpLog, sTest == PROD ? LOG_TO_HTTP : LOG_TO_BOTH);

static const uint8_t FACTORY_RESET_PIN = A0;
static const unsigned long FACTORY_RESET_HOLD_MS = 5000;

static const uint8_t MODEM_SSR_PIN = A5;
static const uint8_t ROUTER_SSR_PIN = 5;
static IndicatorLED sRGB;

static Connector sConnector(sRGB, Log);

static int sFailureCnt = 0;
static const char *sPendingEmail = NULL;


static const char *to_str(const IPAddress &ip)
{
  static char buf[20];
  sprintf(buf, "%d.%d.%d.%d", ip[0], ip[1], ip[2], ip[3]);
  return buf;
}

static const char *to_str(const char *s)
{
  return s;
}


static void enableRouter(bool on) {
  if (on) {
    Log.printf("INFO(%ld): enableRouter turn on\n", millis());
    digitalWrite(ROUTER_SSR_PIN, LOW);  // SSR is normally-closed, so LOW releases it to close
  } else {
    Log.printf("INFO(%ld): enableRouter turn off\n", millis());
    digitalWrite(ROUTER_SSR_PIN, HIGH);  // SSR is normally-closed, so HIGH drives it to open
  }
}


static void enableModem(bool on) {
  if (on) {
    Log.printf("INFO(%ld): enableModem turn on\n", millis());
    digitalWrite(MODEM_SSR_PIN, LOW);  // SSR is normally-closed, so LOW releases it to close
  } else {
    Log.printf("INFO(%ld): enableModem turn off\n", millis());
    digitalWrite(MODEM_SSR_PIN, HIGH);  // SSR is normally-closed, so HIGH drives it to open
  }
}


static void send_reset_email() {
  Log.printf("WARNING(%ld): system restarted; sending an email...\n", millis());
  
  EmailRelay Mailer(EMAIL_HOST, EMAIL_PORT, EMAIL_PATH, SECRET_EMAIL_KEY);
  Mailer.begin();

  char subject[30];
  sprintf(subject, "ALERT %s", PROGNAME);
  if (!Mailer.send(subject, "system restarted")) {
    Log.printf("ERROR(%ld): EmailRelay failed\n", millis());
  } 
}


static void send_email(const char *reason) {
  Log.printf("WARNING(%ld): failure detected(%s); sending an email...\n", millis(), reason);
  
  EmailRelay Mailer(EMAIL_HOST, EMAIL_PORT, EMAIL_PATH, SECRET_EMAIL_KEY);
  Mailer.begin();

  char subject[30];
  sprintf(subject, "ALERT %s", PROGNAME);
  if (!Mailer.send(subject, reason)) {
    Log.printf("ERROR(%ld): EmailRelay failed\n", millis());
  } 
}


static void bounce_modem() {
  Log.printf("WARNING(%ld): bouncing modem...\n", millis());

  bool redState = sRGB.getRed();
  bool greenState = sRGB.getGreen();
  bool blueState = sRGB.getBlue();
  sRGB.off();
  sRGB.setRed(true);

  enableModem(false);
  
  // leave off for 15 seconds
  delay(15000);
  
  enableModem(true);
  
  // wait for 210s while modem initializes
  Log.printf("INFO(%ld): waiting 3 minutes for modem initialization...\n", millis());
  delay(210000);

  sPendingEmail = "modem failure";

  sRGB.setRed(redState);
  sRGB.setGreen(greenState);
  sRGB.setBlue(blueState);

  Log.printf("INFO(%ld): continuing with normal operations after bouncing modem...\n", millis());
}

static void bounce_router() {
  Log.printf("WARNING(%ld): bouncing router...\n", millis());

  bool redState = sRGB.getRed();
  bool greenState = sRGB.getGreen();
  bool blueState = sRGB.getBlue();
  sRGB.off();  
  sRGB.setRed(true);

  enableRouter(false);
  
  // leave off for 15 seconds
  delay(15000);
  
  enableRouter(true);
  
  // wait for 210s while router initializes
  Log.printf("INFO(%ld): waiting 3 minuites for router initialization...\n", millis());
  delay(210000);
  
  sPendingEmail = "router failure";
  
  sRGB.setRed(redState);
  sRGB.setGreen(greenState);
  sRGB.setBlue(blueState);

  Log.printf("INFO(%ld): continuing with normal operations after bouncing router...\n", millis());
}

static void nextState(State nextState, long delay) {
  sStateAfterWait = nextState;
  sState = Wait;
  sWait_ms = delay;  
}


void printWiFiStatus() {
  // print the SSID of the network you're attached to:
  Log.printf("INFO(%ld): SSID: %s\n", millis(), WiFi.SSID());

  // print your WiFi shield's IP address:
  Log.printf("INFO(%ld): IP Address: %s\n", millis(), to_str(WiFi.localIP()));

  // print the received signal strength:
  long rssi = WiFi.RSSI();
  Log.printf("INFO(%ld): signal strength (RSSI): %ld dBm\n\n", millis(), rssi);
}


static int ping_test(const char *devname, const char *ipstr, State thisState, State successState, void (*bounceFtor)()) {
  //Log.printf("INFO(%ld): pinging %s @ %s\n", millis(), devname, ipstr);
  if (WiFi.ping(ipstr) > 0) {
    Log.printf("INFO(%ld): successful ping of %s @ %s\n", millis(), devname, ipstr);
    nextState(successState, 2*1000);
    sFailureCnt = 0;
  } else {
    sFailureCnt++;
    Log.printf("WARNING(%ld): couldn't connect to %s @ %s (failure %d/%d)\n",
               millis(), devname, ipstr, sFailureCnt, NUM_FAILURES_TO_BOUNCE);
    if (sFailureCnt < NUM_FAILURES_TO_BOUNCE) {
      Log.printf("INFO(%ld): retrying in 60s...\n", millis());
      nextState(thisState, 60*1000);
    } else {
      // all tries exhausted...  have to bounce the device
      Log.printf("WARNING(%ld): All %s tries exhausted; bouncing %s...\n", millis(), devname, devname);
      bounceFtor();
      sFailureCnt = 0;
      nextState(Initialize, 1*1000);
    }
  }
  return 0;
}


static bool checkFactoryResetButton() {
  pinMode(FACTORY_RESET_PIN, INPUT_PULLUP);

  // Let the pin settle after reset.
  delay(20);

  unsigned long start = millis();

  Log.printf("INFO(%ld): Reset button held; considering factory-reset\n", millis());

  while (digitalRead(FACTORY_RESET_PIN) == LOW) {
    unsigned long held = millis() - start;

    if (held >= FACTORY_RESET_HOLD_MS) {
      Log.printf("WARNING(%ld): Factory reset requested\n", millis());

      // Wait for release before continuing, so the button press
      // does not immediately trigger another reset cycle.
      while (digitalRead(FACTORY_RESET_PIN) == LOW) {
        delay(50);
        sRGB.toggleRed();
      }
      sRGB.setRed(false);

      delay(100);
      return true;
    }

    delay(20);
  }

  Log.printf("INFO(%ld): Reset button released before factory-reset timeout\n", millis());
  return false;
}






void setup() {
  //Configure pins for Adafruit ATWINC1500 Feather
  WiFi.setPins(8,7,4,2);

  pinMode(MODEM_SSR_PIN, OUTPUT);
  digitalWrite(MODEM_SSR_PIN, LOW);
  pinMode(ROUTER_SSR_PIN, OUTPUT);
  digitalWrite(ROUTER_SSR_PIN, LOW);

  sState = Initialize;

  bool factoryResetEnabled = checkFactoryResetButton();

  if ((Log.getMode() == LOG_TO_BOTH) || (Log.getMode() == LOG_TO_SERIAL)) {
    //Initialize serial and wait for port to open:
    Serial.begin(9600);
    while (!Serial) {
      ; // wait for serial port to connect. Needed for native USB port only
    }

    Serial.printf("\n\n");
  }


  // check for the presence of the shield:
  if (WiFi.status() == WL_NO_SHIELD) {
    Log.printf("FATAL(%ld): WiFi shield not present; can't proceed.\n", millis());

    // can't/don't continue:
    while (true) {}
  }

  if (sTest == PROD) {
    if (factoryResetEnabled) {
      sConnector.factoryReset();
    }
    sConnector.connectUsingStoredCreds(sTest);
  } else {
    // attempt to connect to WiFi network using secret creds
    sConnector.connectWithCreds(SECRET_SSID, SECRET_PASS);
  }
  // control will only return if connected
  sRGB.setGreen(true);

  
  WiFi.maxLowPowerMode();
  sHttpLog.set_wifi_available(); // now all logging can go thru the Log facace

  printWiFiStatus();

  send_reset_email();

  // consider testing mode: should one of the addresses be perturbed, or directly trigger something
  if (sTest == test_ROUTER) {
    // RouterIP is already set to *.*.*.111
  } else if (sTest == test_IP) {
    // InternetIP is already set to *.*.*.11
  } else if (sTest == test_MODEM) {
    // ModemIP is already set to *.*.*.111
  } else if (sTest == test_DNS) {
    // DNS is already set to google.comfoo
  } else if (sTest == test_BOUNCE_MODEM) {
    bounce_modem();
  } else if (sTest == test_BOUNCE_ROUTER) {
    bounce_router();
  } else if (sTest == test_EMAIL) {      
    Log.printf("INFO(%ld): testing email delivery\n", millis());
    send_email("testing email");
  }

}


void loop() {

  switch (sState) {
    case Initialize: 
      sStateAfterWait = APConnect;
      sState = Wait;
      sWait_ms = 1000;
      break;
    case APConnect:
      if (!sConnector.isConnected()) {
        sRGB.off();
        sRGB.setBlue(true);
       
        sFailureCnt++;
        Log.printf("INFO(%ld): AP disconnect detected (failure %d/%d)\n",
                   millis(), sFailureCnt, NUM_FAILURES_TO_BOUNCE);

        if (sFailureCnt < NUM_FAILURES_TO_BOUNCE) {
          Log.printf("WARNING(%d): attempting wifi reconnect\n", millis());

          // make one try at reconnecting
          const int num_tries = 1;
          bool connected = sConnector.reconnect(num_tries);
          if (connected) {
            Log.printf("INFO(%ld): success; continuing as normal\n", millis());
            sRGB.off();
            sRGB.setGreen(true);
            sPendingEmail = "AP disconnect";
            nextState(RouterPing, 2*1000);
          } else {
            Log.printf("WARNING(%ld): failed; retrying in 60s..\n", millis());
            nextState(APConnect, 60*1000);
          }

        } else {
          // all tries exhausted...  have to bounce the router
          Log.printf("WARNING(%ld): All AP connect tests exhausted; bouncing router...\n", millis());
                     bounce_router();

          // reconnect -- try forever
          sConnector.reconnect();

          sRGB.off();
          sRGB.setGreen(true);
          sPendingEmail = "AP disconnect";

          sFailureCnt = 0;
          nextState(Initialize, 1*1000);
        }
      } else {
        sRGB.setBlue(false);
        sRGB.setGreen(true);

        Log.printf("INFO(%ld): AP connection detected\n", millis());
        nextState(RouterPing, 2*1000);
        sFailureCnt = 0;
      }
      break;
    case RouterPing: 
      ping_test("router", to_str(RouterIP()), RouterPing, ModemPing, bounce_router);
      break;
    case ModemPing: 
      ping_test("modem", to_str(ModemIP()), ModemPing, InternetPing, bounce_modem);
      break;
    case InternetPing: 
      ping_test("internet", to_str(Internet()), InternetPing, DnsPing, bounce_modem);
      break;
    case DnsPing: 
      ping_test("dns", DNS(), DnsPing, Sleep, bounce_modem);
      break;
    case Sleep: 
      Log.printf("INFO(%ld): sleeping until next check in %d mins\n", millis(), TIME_BETWEEN_MONITOR_ATTEMPTS_ms/1000/60);
      nextState(Initialize, TIME_BETWEEN_MONITOR_ATTEMPTS_ms);
      sFailureCnt = 0;
      break;
    case Wait: 
      Log.flush();
      delay(1);
      if (--sWait_ms == 0) {
        if (sPendingEmail) {
          send_email(sPendingEmail);
          sWait_ms = 30000; // wait some more for email to send+settle
          sPendingEmail = NULL;
        } else {
          sState = sStateAfterWait;
          sStateAfterWait = Initialize;
        }
      }
      break;
  }

}

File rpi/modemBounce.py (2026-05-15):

#!/usr/bin/python

import os
import sys
import requests
import time
import datetime
import subprocess
import socket
from gpiozero import LED

progname = "modemBounce.py"

Internet = "8.8.8.8"
DNS = "google.com"
ModemIP = "192.168.100.1"
RouterIP = "10.0.0.1"

shellyBaseurl = 'http://10.0.0.212'



def usage():
    print("Usage: ")
    print("> modemBounce [-tDNS -tROUTER -tIP -tMODEM -tBOUNCE-MODEM -tBOUNCE-ROUTER]")
    print("")
    print("where")
    print("   -tDNS\t\ttest DNS failure")
    print("   -tROUTER\t\ttest Router failure")
    print("   -tIP\t\t\ttest IP failure")
    print("   -tMODEM\t\ttest Modem failure")
    print("   -tBOUNCE-MODEM\ttest the modem bounce")
    print("   -tBOUNCE-ROUTER\ttest the router bounce")
    print("   -e\t\t\ttest email sendx")
    
    

def nowstr():
    fmt = '%Y-%b-%d %H:%M:%S'
    return datetime.datetime.today().strftime('%Y-%b-%d %H:%M:%S')


def sendEmail(reason):
    print("WARNING(%s): connectivity failure detected(%s); preparing an email..." % (nowstr(), reason))
    filename = "/tmp/"+progname+"-msg.txt"
    f = open(filename, "w")
    f.write("To: j.cicchiello@ieee.org\n")
    print("INFO(%s): To: j.cicchiello@ieee.org" % (nowstr()))
    f.write("From: jcicchiello@ptd.net\n")
    print("INFO(%s): From: jcicchiello@ptd.net" % (nowstr()))
    f.write("Subject: ALERT: %s\n" % progname)
    print("INFO(%s): Subject: ALERT %s" % (nowstr(), progname))
    f.write("\n")
    print("INFO(%s): " % (nowstr()))
    f.write("INFO(%s): %s has detected, and recovered from, a connectivity failure (%s)!\n" % (nowstr(), progname, reason))
    print("INFO(%s): %s has detected, and recovered from, a connectivity failure (%s)!" % (nowstr(), progname, reason))
    f.write("\n")
    print("INFO(%s): " % (nowstr()))
    f.write("\n")
    print("INFO(%s): " % (nowstr()))
    f.close()
    time.sleep(5)
    with open(filename, 'r') as infile:
        subprocess.Popen(['/usr/bin/msmtp', 'j.cicchiello@gmail.com'],
                         stdin=infile, stdout=sys.stdout, stderr=sys.stderr)

        
def bounceModem():
    print("WARNING(%s): Turning off the modem..." % nowstr())
    
    # Turn off the modem
    requests.get('%s/rpc/Switch.Set?id=0&on=false' % shellyBaseurl)
    
    # .. wait a bit
    print("WARNING(%s): waiting 15s..." % nowstr())
    time.sleep(15)
    
    print("WARNING(%s): turning modems back on..." % nowstr())
    
    # Turn on the modem
    requests.get('%s/rpc/Switch.Set?id=0&on=true' % shellyBaseurl)
    
    # wait 210s to (hopefully) fully come back online, then send an alert email
    # (Note shorter waits didn't work reliably)
    print("WARNING(%s): waiting 210s..." % nowstr())
    time.sleep(210)
    
    print("WARNING(%s): sending alert email..." % nowstr())
    sendEmail("modem failure")
    time.sleep(30)


def bounceRouter():
    print("WARNING(%s): Turning off the router..." % nowstr())

    # Turn off the router
    os.system("pinctrl set 23 dl")

    # .. wait a bit
    print("WARNING(%s): waiting 15s..." % nowstr())
    time.sleep(15)
    
    print("WARNING(%s): turning router back on..." % nowstr())
    os.system("pinctrl set 23 dh")

    # wait 210s to (hopefully) fully come back online, then send an alert email
    # (Note shorter waits didn't work reliably)
    print("WARNING(%s): waiting 210s..." % nowstr())
    time.sleep(210)
    
    print("WARNING(%s): sending alert email..." % nowstr())
    sendEmail("router failure")
    time.sleep(30)

    
def dns_works(hostname):
    try:
        socket.gethostbyname(hostname)
        return True
    except socket.gaierror:
        return False


def ping(host, count=3, timeout_sec=2):
    """
    Return True if host responds to ping, False otherwise.
    Linux/Raspberry Pi version.
    """
    result = subprocess.run(
        [
            "ping",
            "-c", str(count),        # number of pings
            "-W", str(timeout_sec),  # timeout per ping, seconds
            host,
        ],
        stdout=subprocess.DEVNULL,
        stderr=subprocess.DEVNULL,
    )
    return result.returncode == 0


def test(routerIP, modemIP, internet, dns, triesLeft):
    #print("TRACE(test): routerIP(%s), modemIP(%s), internet(%s), dns(%s), triesLeft(%d)" % \
    #      (routerIP, modemIP, internet, dns, triesLeft))
    if not ping(routerIP):
        print("WARNING(%s): Router test failed (%d); pausing for one minute..." % (nowstr(), triesLeft))
        if triesLeft > 0:
            time.sleep(60)
            test(routerIP, modemIP, internet, dns, triesLeft-1)
        else:
            # all tries exhausted...   have to bounce the router
            print("WARNING(%s): All router tries exhausted; bouncing router..." % nowstr())
            bounceRouter()
    elif not ping(modemIP):
        print("WARNING(%s): Modem test failed (%d); pausing for one minute..." % (nowstr(), triesLeft))
        if triesLeft > 0:
            time.sleep(60)
            test(routerIP, modemIP, internet, dns, triesLeft-1)
        else:
            # all tries exhausted...   have to bounce the modem
            print("WARNING(%s): All modem tries exhausted; bouncing modem..." % nowstr())
            bounceModem()
    elif not ping(internet):
        print("WARNING(%s): Internet test failed (%d); pausing for one minute..." % (nowstr(), triesLeft))
        if triesLeft > 0:
            time.sleep(60)
            test(routerIP, modemIP, internet, dns, triesLeft-1)
        else:
            # all tries exhausted...   have to bounce the modem
            print("WARNING(%s): All internet tries exhausted; bouncing modem..." % nowstr())
            bounceModem()
    elif not dns_works(dns):
        print("WARNING(%s): DNS test failed (%d); pausing for one minute..." % (nowstr(), triesLeft))
        if triesLeft > 0:
            time.sleep(60)
            test(routerIP, modemIP, internet, dns, triesLeft-1)
        else:
            # all tries exhausted...   have to bounce the modem
            print("WARNING(%s): All DNS tries exhausted; bouncing modem..." % nowstr())
            bounceModem()
    else:
        # healthy
        print("INFO(%s): Connectivity test passed" % (nowstr()))
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

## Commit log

2023-10-13 - added calls to toggle power of the Shelly Plus US smart plug - added email alert message - cleaned up print messages - added tests for sending email and testing failure behavior by testing against 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
    [modemBounce.py]
2026-05-13 - small change to INFO print
2026-05-14 - enhance to support detection of both modem, IP, DNS and router failures - support independent bounce of modem or router
    [modemBounce.py]
2026-05-15 - adding pinctrl commands to ensure the SSR is enabled except when we're forcing a reboot
    [modemBounce.py]
2026-05-27 Initial commit of logger service to be called by modemBounce Arduino-style embedded service
2026-05-27 Initial commit of feather Arduino-style code
2026-05-28 - enhance provisioning logic: if the WifiCredStore has data, then reset should lead to repeated tries (to deal with the case where power has just been restored, but the wifi hasn't come back online y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
    [bouncy.ino]
2026-05-29 - Added RGB LED Indicator light and logic
2026-05-29 - implemented email-relay service so that low-resource IOT devices (like Adafruit Feather) can have crude email delivery capabilities
2026-05-30 - rearranged GPIOs to minimize circuit routing - added GPIO control of the SSRs via 2n2222 drivers
2026-05-30 - added email-send when powered up (so I can detect power failures)
    [bouncy.ino]
2026-06-09 - several pins reassigned for easier pcb layout
2026-06-10 - attached Claude to document everything
    [bouncy.FCStd, bouncy_v1.1.FCStd, bouncy_v1.2.FCStd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]
2026-06-10 - adding the HTML version of the reference card to place on the bottom of the device
